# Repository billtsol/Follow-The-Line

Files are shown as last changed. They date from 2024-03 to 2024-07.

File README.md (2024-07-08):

# Arduino Follow-the-Line Project with QTR Reflectance Sensor

This project is an example of how to use an Arduino board, QTR reflectance sensor, and a motor driver shield to create a simple follow-the-line robot.

## Requirements

To build this project, you will need the following components:

- Arduino board
- QTR reflectance sensor
- Motor driver shield
- Wheels
- Motors
- Jumper wires
- Battery

## Circuit Diagram

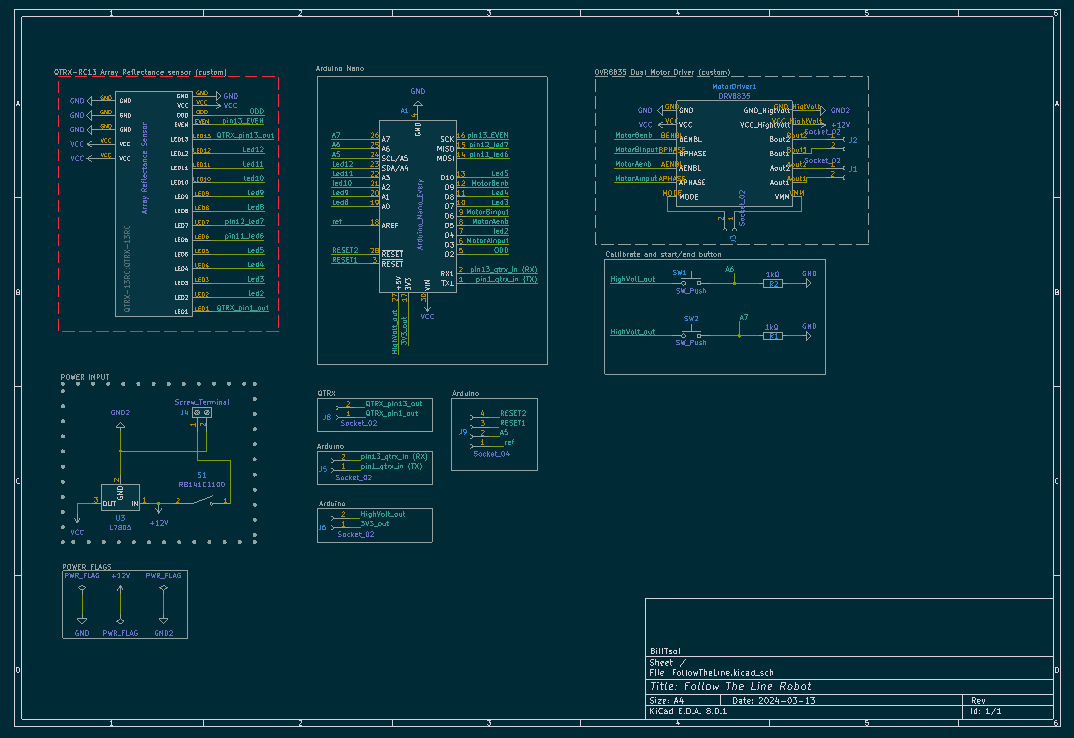
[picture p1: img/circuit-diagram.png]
Circuit Diagram


## PCB

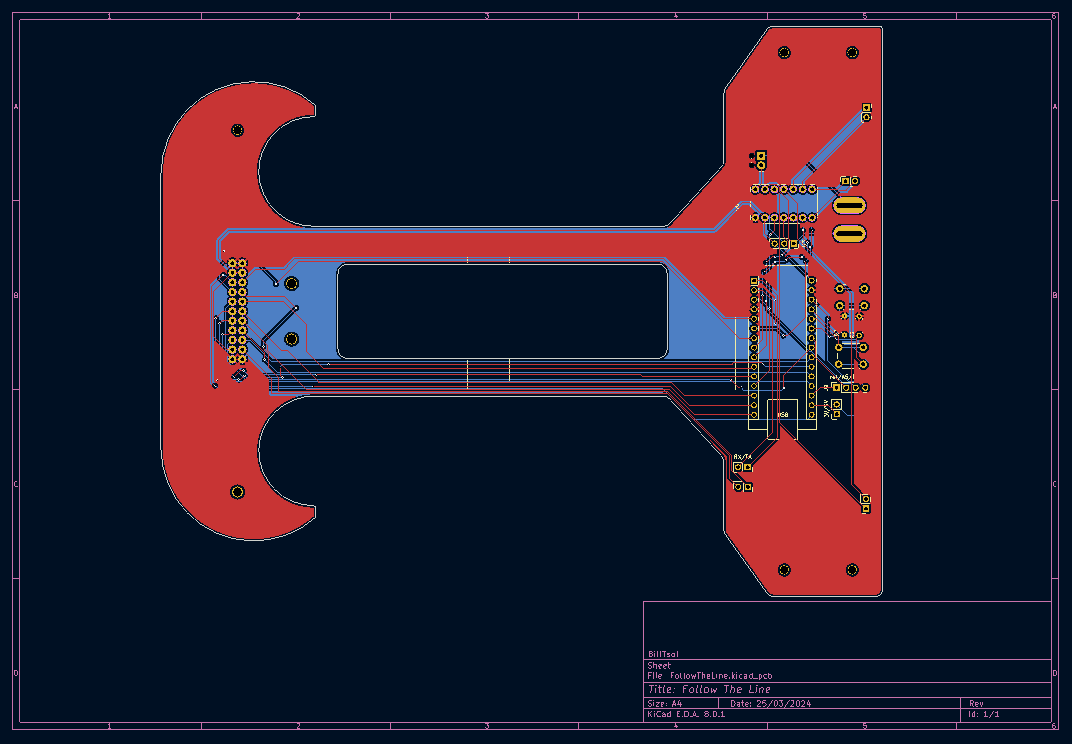
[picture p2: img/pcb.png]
PCB


## Code

The code for this project is available in the `follow_the_line.ino` file.
You can also open the `qtr_xA_example.ino` file that includes an example of how to use the QTR reflectance sensor as an analog sensor to detect the position of a line.

## Installation

1. Download the Arduino IDE from the official website and install it on your computer.
2. Connect your Arduino board to your computer via USB cable.
3. Open the Arduino IDE and open the `follow_the_line.ino` file.
4. Upload the code to your Arduino board by clicking the "Upload" button in the IDE.

## Usage

1. Connect the QTR reflectance sensor and the motor driver shield to your Arduino board according to the circuit diagram.
2. Attach the wheels and motors to the chassis.
3. Connect the motors to the motor driver shield.
4. Connect the battery to the motor driver shield.
5. Turn on the power and place the robot on a black line on a white background.
6. The robot will follow the line until it reaches the end of the line.

## Troubleshooting

If the robot does not follow the line correctly, you may need to adjust the threshold values in the code or adjust the position of the QTR reflectance sensor.

## Feature thoughts for this project:

1. Add some LEDs to make the car follow the line in the dark: By adding some LEDs to the front of the robot, it can detect the line even in low light conditions. The LEDs can be programmed to turn on when the QTR sensor detects the line and turn off when it doesn't. This feature can improve the robot's performance in darker environments.

2. Add some obstacle sensors to avoid objects in line: By adding some obstacle sensors to the sides of the robot, it can detect if there are any obstacles in its path and avoid them while staying on the line. This feature can improve the safety of the robot and prevent it from crashing into objects while following the line.

## Final Images

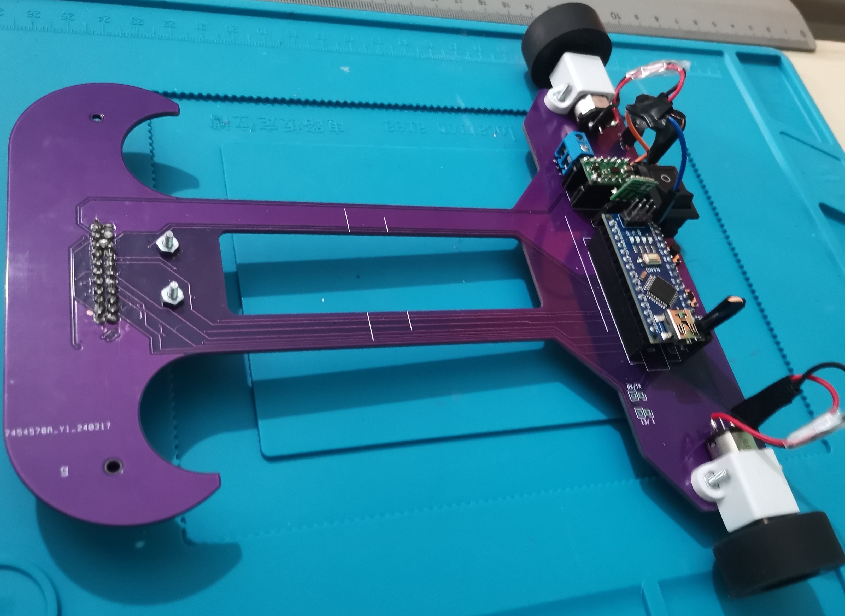
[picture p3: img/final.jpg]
final

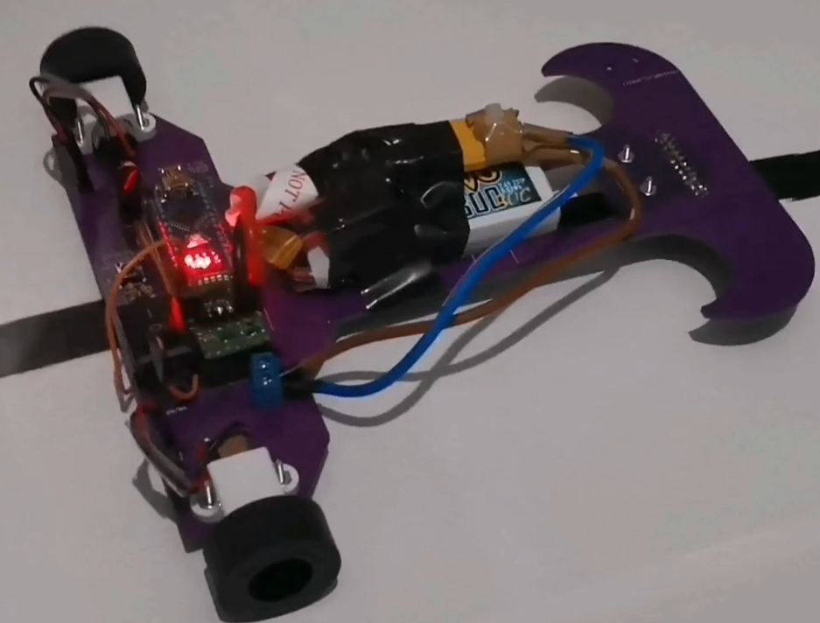
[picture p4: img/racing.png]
racing


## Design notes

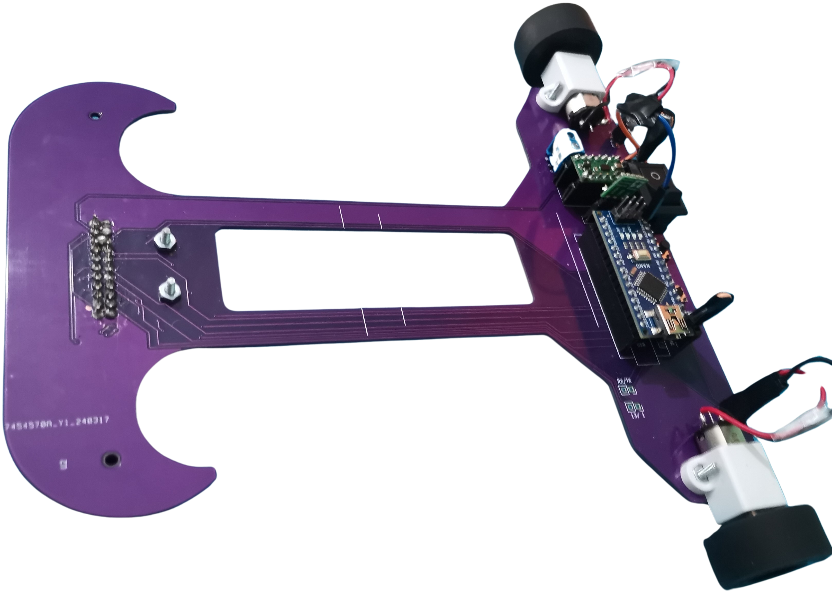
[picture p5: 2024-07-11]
img/final-removebg.png

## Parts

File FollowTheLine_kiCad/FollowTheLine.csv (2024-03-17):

Source: | C:\Users\iis22\OneDrive\Documents\github\Follow-The-Line\FollowTheLine_kiCad\FollowTheLine.kicad_sch
Date: | 2024-03-17T01:34:20+0200
Tool: | Eeschema 8.0.0
Generator: | C:\Program Files\KiCad\8.0\bin\scripting\plugins/bom_csv_grouped_by_value_with_fp.py
Component Count: | 17
Ref | Qnty | Value | Cmp name | Footprint | Description | Vendor | DNP
A1 | 1 | Arduino_Nano_Every | Arduino_Nano_Every | Module:Arduino_Nano | Arduino Nano Every
J1, J2, J3, J5, J6, J8 | 6 | Socket_02 | Conn_01x02_Socket | Connector_PinSocket_2.54mm:PinSocket_1x02_P2.54mm_Vertical | Generic connector, single row, 01x02, script generated
J4 | 1 | Screw_Terminal | Screw_Terminal_01x02 | TerminalBlock_Phoenix:TerminalBlock_Phoenix_MPT-0,5-2-2.54_1x02_P2.54mm_Horizontal | Generic screw terminal, single row, 01x02, script generated (kicad-library-utils/schlib/autogen/connector/)
J9 | 1 | Socket_04 | Conn_01x04_Socket | Connector_PinSocket_2.54mm:PinSocket_1x04_P2.54mm_Vertical | Generic connector, single row, 01x04, script generated
MotorDriver1 | 1 | DRV8835 | DRV8835 | Library:DRV8835
R1, R2 | 2 | 1kΩ | R | Resistor_THT:R_Axial_DIN0204_L3.6mm_D1.6mm_P5.08mm_Horizontal | Resistor
S1 | 1 | RB141C1100 | RB141C1100 | RB141C1100:SW_RB141C1100
SW1, SW2 | 2 | SW_Push | SW_Push | Button_Switch_THT:SW_PUSH_6mm | Push button switch, generic, two pins
U2 | 1 | Array Reflectance Sensor | QTR-8A | QTRX-13RC:QTRX-13RC
U3 | 1 | L7805 | L7805 | Connector_PinSocket_2.54mm:PinSocket_1x03_P2.54mm_Vertical | Positive 1.5A 35V Linear Regulator, Fixed Output 5V, TO-220/TO-263/TO-252

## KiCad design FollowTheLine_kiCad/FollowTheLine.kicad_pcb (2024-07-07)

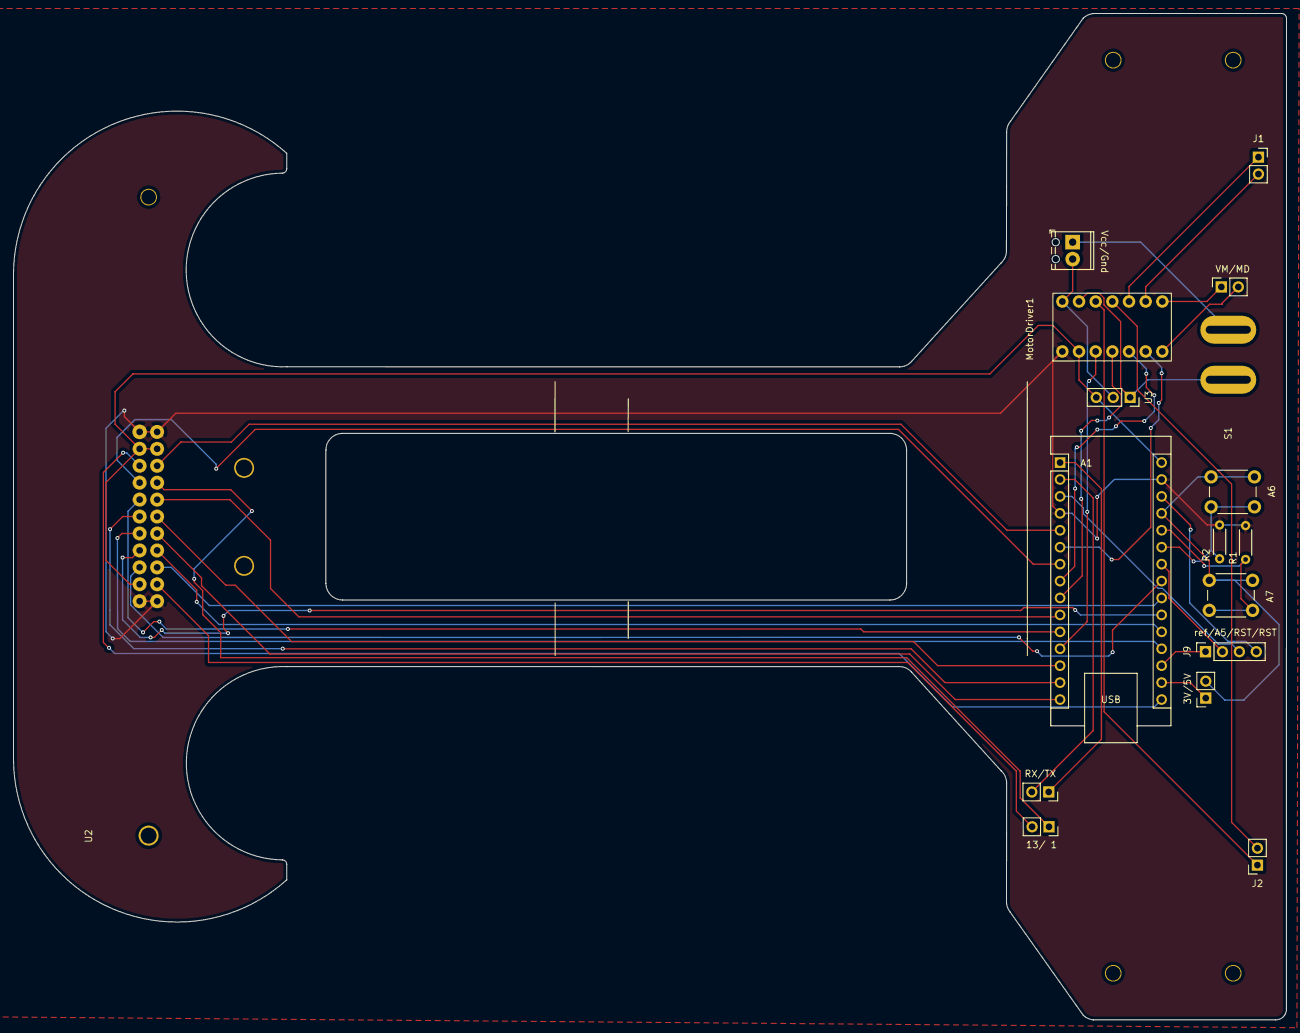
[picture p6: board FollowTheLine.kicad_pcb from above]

Board: 2 copper layers, 191.0 x 151.0 mm, 17 parts (0 on the bottom side), 40 nets.

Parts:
A1: Arduino_Nano_Every; Arduino_Nano
A6, A7: SW_Push; SW_PUSH_6mm
J1, J2, J3, J5, J6, J18: Socket_02; PinSocket_1x02_P2.54mm_Vertical
J4: Screw_Terminal; TerminalBlock_Phoenix_MPT-0,5-2-2.54_1x02_P2.54mm_Horizontal
J9: Socket_04; PinSocket_1x04_P2.54mm_Vertical
MotorDriver1: DRV8835
R1, R2: 1kΩ; R_Axial_DIN0204_L3.6mm_D1.6mm_P5.08mm_Horizontal
S1: RB141C1100; SW_RB141C1100
U2: Array Reflectance Sensor; QTRX-13RC
U3: L7805; PinSocket_1x03_P2.54mm_Vertical

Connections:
+12V: MotorDriver1.VCC_HightVolt, S1.2, U3.1 (IN)
/3V3_out: A1.17 (3V3), J6.1
/A5: A1.24 (SCL/A5), J9.2
/A6: A1.25 (A6), A6.2, R2.1
/A7: A1.26 (A7), A7.2, R1.1
/HighVolt_out: A1.27 (+5V), A6.1, A7.1, J6.2
/Led3: A1.10 (D7), U2.LED3
/Led4: A1.11 (D8), U2.LED4
/Led5: A1.13 (D10), U2.LED5
/Led8: A1.19 (A0), U2.LED8
/Led9: A1.20 (A1), U2.LED9
/Led11: A1.22 (A3), U2.LED11
/Led12: A1.23 (SDA/A4), U2.LED12
/MotorAenb: A1.8 (D5), MotorDriver1.AENBL
/MotorAinput: A1.6 (D3), MotorDriver1.APHASE
/MotorBenb: A1.12 (D9), MotorDriver1.BENBL
/MotorBinput: A1.9 (D6), MotorDriver1.BPHASE
/ODD: A1.5 (D2), U2.ODD
/QTRX_pin1_out: J18.1, U2.LED1
/QTRX_pin13_out: J18.2, U2.LED13
/RESET1: A1.3 (~RESET), J9.3
/RESET2: A1.28 (~RESET), J9.4
/led2: A1.7 (D4), U2.LED2
/led10: A1.21 (A2), U2.LED10
/pin1_qtrx_in (TX): A1.1 (TX1), J5.1
/pin11_led6: A1.14 (MOSI), U2.LED6
/pin12_led7: A1.15 (MISO), U2.LED7
/pin13_EVEN: A1.16 (SCK), U2.EVEN
/pin13_qtrx_in (RX): A1.2 (RX1), J5.2
/ref: A1.18 (AREF), J9.1
GND: A1.4 (GND), A1.29 (GND), MotorDriver1.GND, R1.2, R2.2, U2.GND
GND2: J4.2, MotorDriver1.GND_HigtVolt, U3.2 (GND)
unnamed: J1.1, MotorDriver1.Aout2
unnamed: J1.2, MotorDriver1.Aout1
unnamed: J2.1, MotorDriver1.Bout2
unnamed: J2.2, MotorDriver1.Bout1
unnamed: J3.1, MotorDriver1.VMM
unnamed: J3.2, MotorDriver1.MODE
unnamed: J4.1, S1.1
VCC: A1.30 (VIN), MotorDriver1.VCC, U2.VCC, U3.3 (OUT)

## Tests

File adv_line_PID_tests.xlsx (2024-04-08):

Kp | Ki | Kd |  | MAX | Base
0.08 | 0.0005 | 0.5 | oxi | 170 | 100
 |  | 0.4 | oxi
 |  | 0.3 | oxi
0.09 |  |  | kati
 |  | 0.5 | oxi
0.1 |  | 0.3 | nai
0.2 |  |  | oxi
 |  | 0.2 | oxi
0.095 |  |  | nai alla den mpainei kentro
 |  | 0.3
0.095 | 0.005 | 0.25 | nai | 200 | 100
0.095 |  | 0.15 | nai | 200 | 100
0.09 | 0.004 | 0.15
0.09 | 0.003 | 0.1 | ΝΑΙ | 200 | 100
0.08 | 0.003 | 0.1 | ΝΑΙ | 255 | 100
0.07 | 0.003 | 0.1 | oxi

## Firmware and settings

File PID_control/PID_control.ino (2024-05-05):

// Length = 5m

/*************************************************************************
 * QRT-X GPIO pins declaration
 *************************************************************************/
#include <QTRSensors.h>

QTRSensors qtr;
const uint8_t SensorCount = 11;
uint16_t sensorValues[SensorCount];

const int oddPin = 2;
const int evenPin = 2;

/*************************************************************************
 * DRV8835 GPIO pins declaration
 *************************************************************************/
// int mode = ; Auto ON

// Left Motor
int aphase = 3;
int aenbl = 5;

// Right Motor
int bphase = 6;
int benbl = 9;

int base_speed = 100;

int max_speed = 200;
int min_speed = -200;

/*************************************************************************
* PID controler variables
*************************************************************************/
float Kp = 0.09;  //related to the proportional control term;
                   //change the value by trial-and-error (ex: 0.07). 0.03
float Ki = 0.0003; //related to the integral control term;
                   //change the value by trial-and-error (ex: 0.0008). 0.00001
float Kd = 0.08;  //related to the derivative control term;
                   //change the value by trial-and-error (ex: 0.6). 0.3

int P = 0;
int I = 0;
int D = 0;

int lastError = 0;

/*************************************************************************
* Buttons pins declaration
*************************************************************************/
int buttoncalibrate = A7;
int startButton = A6;

int stop = 0;
unsigned long startTime = 0;
int timer_duration = 7000; // Define timer duration in milliseconds (5 seconds)

void setup() {
  // Serial.begin(9600);

  // QTRX Set up
  qtr.setTypeRC();
  qtr.setSensorPins((const uint8_t[]){4, 7, 8, 10, 11, 12, A0, A1, A2, A3, A4}, SensorCount);
  qtr.setEmitterPin(oddPin);

  // Motors Set up
  pinMode(aphase, OUTPUT);
  pinMode(aenbl, OUTPUT);
  pinMode(bphase, OUTPUT);
  pinMode(benbl, OUTPUT);

  pinMode(13,OUTPUT);

  pinMode(buttoncalibrate, INPUT);
  pinMode(startButton, INPUT);

  digitalWrite(13, LOW);

}

void loop() {
  while( analogRead(buttoncalibrate) == 0); // Start Calibration A6

  calibration(); // Calibrate the robot for 10 seconds

  forward_movement(0,0);

  while( analogRead(startButton) == 0); // Start Calibration A6

  delay(1500);

  startTime = millis();

  while (1){
    unsigned long currentTime = millis();
    if (
      (end() == 1 || stop == 1) &&
      ( currentTime - startTime >= timer_duration )
    ){
      forward_movement(0,0);
      stop = 1;
    }else{
      PID_control();
    }
  }

}

void PID_control(){
  uint16_t position = qtr.readLineBlack(sensorValues);

  int error = 5000 - position;

  P = error;
  I = I + error;
  D = error - lastError;

  lastError = error;

  float motor_speed = P*Kp + I*Ki + D*Kd;
  int motor_speed_A = base_speed - motor_speed;
  int motor_speed_B = base_speed + motor_speed;

  // Set max speed
  if (motor_speed_A > max_speed) { motor_speed_A = max_speed; }
  if (motor_speed_B > max_speed) { motor_speed_B = max_speed; }

  // Set min speed
  if (motor_speed_A < min_speed) { motor_speed_A = min_speed; }
  if (motor_speed_B < min_speed) { motor_speed_B = min_speed; }

  forward_movement(motor_speed_A, motor_speed_B);

  // Serial.print('\n');
  // Serial.print("A: ");
  // Serial.print(motor_speed_A);
  // Serial.print('\n');
  // Serial.print("B: ");
  // Serial.print(motor_speed_B);

  // Serial.print('\n');
}

void custom_corners(){

  // Right
  if (
    sensorValues[6] > 600 &&
    sensorValues[7] > 600 &&
    sensorValues[8] > 600 &&
    sensorValues[9] > 600 &&
    sensorValues[10] > 600 &&

    sensorValues[0] < 600
  ) {
    forward_movement(75, 250);
    delay(250);
  }
  // Left
  if (
    sensorValues[0] > 600 &&
    sensorValues[1] > 600 &&
    sensorValues[2] > 600 &&
    sensorValues[3] > 600 &&
    sensorValues[4] > 600 &&

    sensorValues[10] < 600
  ){
    forward_movement(250, 75);
    delay(250);
  }

  forward_movement(base_speed,base_speed);
}

void forward_movement(int speedA, int speedB) {
  if (speedA < 0) {
    speedA = 0 - speedA;
    digitalWrite(aphase, LOW);
  }
  else {
    digitalWrite(aphase, HIGH);
  }

  if (speedB < 0) {
    speedB = 0 - speedB;
    digitalWrite(bphase, HIGH);
  }
  else {
    digitalWrite(bphase, LOW);
  }

  analogWrite(aenbl, speedA);
  analogWrite(benbl, speedB);
}

void calibration() {
  digitalWrite(13,HIGH);
  // int r = -1;
  // int l = 1;
  for (uint16_t i = 0; i < 400; i++) {
  //   if (i % 20 == 0){
  //     forward_movement(75 * r, 75 *  l);
  //     r = -r;
  //     l = -l;
  //   }
    qtr.calibrate();
  }
  digitalWrite(13,LOW);
}

int end(){
  int zero_one = sensorValues[0] + sensorValues[1] ; // Black
  int two = sensorValues[2]; // White ?
  int three = sensorValues[3]; // White
  int seven = sensorValues[7]; // White
  int eight = sensorValues[8]; // White ?
  int nine_ten =  + sensorValues[9] + sensorValues[10]; // Black

  if (
    (zero_one > 900) &&
    (sensorValues[5] > 500) &&
    (nine_ten > 900)
  ){
    return 1;
  }
  return 0;
}

//  Testing functions
void qtrx_test(){
  uint16_t position = qtr.readLineBlack(sensorValues);

  for (uint8_t i = 0; i < SensorCount; i++)
  {

    Serial.print(sensorValues[i]);
    Serial.print('\t');
  }
  Serial.println(position);

  delay(250);
}

void pid_test(int position,int motor_speed){

  Serial.print("\n");
  Serial.print("Line: ");
  Serial.println(position);
  Serial.print("\n");

  Serial.print("P: ");
  Serial.print(P);
  Serial.print('\t');
  Serial.print("I: ");
  Serial.print(I);
  Serial.print('\t');
  Serial.print("D: ");
  Serial.print(D);
  Serial.print('\n');

  Serial.print("Kp: ");
  Serial.print(Kp);
  Serial.print('\t');
  Serial.print("Ki: ");
  Serial.print(Ki);
  Serial.print('\t');
  Serial.print("Kd: ");
  Serial.print(Kd);
  Serial.print('\t');

  Serial.print("sum: ");
  Serial.print(motor_speed);
  Serial.print('\n');
  Serial.print('\n');

  // delay(500);
}

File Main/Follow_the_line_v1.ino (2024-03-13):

#include <QTRSensors.h> //Make sure to install the library

/*************************************************************************
* QTR GPIO pins declaration
*************************************************************************/

QTRSensors qtr;
const uint8_t SensorCount = 11;
uint16_t sensorValues[SensorCount];

const int oddPin = 2;
const int evenPin = 1;

/*************************************************************************
* DRV8835 GPIO pins declaration
*************************************************************************/
int mode = 13;
int aphase = 7;
int aenbl = 10;
int bphase = 4;
int benbl = 9;

/*************************************************************************
* Buttons pins declaration
*************************************************************************/
int buttoncalibrate = 12; //or pin A3
int buttonstart = 12;

/*************************************************************************
* PID controler variables
*************************************************************************/
float Kp = 0.0007; //related to the proportional control term; 
              //change the value by trial-and-error (ex: 0.07).
float Ki = 0.001; //related to the integral control term; 
              //change the value by trial-and-error (ex: 0.0008).
float Kd = 0.007; //related to the derivative control term; 
              //change the value by trial-and-error (ex: 0.6).

int P = 0;
int I = 0;
int D = 0;

int lastError = 0;

int base_speed_A = 40;
int base_speed_B = 40;

void setup() {
  Serial.begin(9600);
  
  qtr.setTypeRC();
  qtr.setSensorPins((const uint8_t[]){ A0, A1, A2, A3, A4, A5, 3, 5, 6, 8, 11  }, SensorCount);
  qtr.setEmitterPins(oddPin, evenPin);

  pinMode(mode, OUTPUT);
  pinMode(aphase, OUTPUT);
  pinMode(aenbl, OUTPUT);
  pinMode(bphase, OUTPUT);
  pinMode(benbl, OUTPUT);

  digitalWrite(mode, HIGH); //one of the two control interfaces 

  pinMode(LED_BUILTIN, OUTPUT);

  while (digitalRead(buttoncalibrate) == LOW) { } // the main function won't start until the robot is calibrated

  calibration(); //calibrate the robot for 10 seconds

  while (digitalRead(buttoncalibrate) == LOW) { } // the main function won't start until the robot is calibrated

}

void loop() {
  PID_control();
}

void PID_control(){
  uint16_t position = qtr.readLineBlack(sensorValues); 

  int error = 5000 - position;
 
  P = error;
  I = I + error;
  D = error - lastError;
  
  lastError = error;

  float motor_speed =( P*Kp + I*Ki + D*Kd)/10;
  int motor_speed_A = base_speed_A - motor_speed; 
  int motor_speed_B = base_speed_B + motor_speed;

  if (position > 4500 && position < 5500){
    motor_speed_A = 40; 
    motor_speed_B = 40;

  }

  if (motor_speed_A > 80) {
    motor_speed_A = 80;
  }
  if (motor_speed_B > 80) {
    motor_speed_B = 80;
  }
  if (motor_speed_A < -80) {
    motor_speed_A = -80;
  }
  if (motor_speed_B < -80) {
    motor_speed_B = -80;
  }


  Serial.print("\n");
  Serial.print("Line: ");
  Serial.println(position);
  Serial.print("\n");
  
  Serial.print("P: ");
  Serial.print(P);
  Serial.print('\t');
  Serial.print("I: ");
  Serial.print(I);
  Serial.print('\t');
  Serial.print("D: ");
  Serial.print(D);
  Serial.print('\n');

  Serial.print("Kp: ");
  Serial.print(Kp);
  Serial.print('\t');
  Serial.print("Ki: ");
  Serial.print(Ki);
  Serial.print('\t');
  Serial.print("Kd: ");
  Serial.print(Kd);
  Serial.print('\t');

  Serial.print("sum: ");
  Serial.print(motor_speed);
  Serial.print('\n');
  Serial.print('\n');
 
  // Serial.print("A: ");
  // Serial.println(motor_speed_A);
  
  // Serial.print("B: ");
  // Serial.println(motor_speed_B);

  forward_movement(motor_speed_A, motor_speed_B);

  // delay(3000);
}


void forward_movement(int speedA, int speedB) {
  if (speedA < 0) {
    speedA = 0 - speedA;
    digitalWrite(aphase, LOW);
  }
  else {
    digitalWrite(aphase, HIGH);
  }
  if (speedB < 0) {
    speedB = 0 - speedB;
    digitalWrite(bphase, HIGH);
  }
  else {
    digitalWrite(bphase, LOW);
  }
  analogWrite(aenbl, speedA);
  analogWrite(benbl, speedB);

  Serial.print("A: ");
  Serial.println(speedA);
  
  Serial.print("B: ");
  Serial.println(speedB);
}

void calibration() {
  digitalWrite(LED_BUILTIN, HIGH);
  for (uint16_t i = 0; i < 400; i++)
  {
    qtr.calibrate();
  }
  digitalWrite(LED_BUILTIN, LOW);
}

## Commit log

2023-04-12 i add the example info for qtr sensor
2023-04-12 add follow the line arduino file
2024-01-23 qtr sensor code
2024-01-25 Control motors
2024-03-06 motor driver test code
2024-03-06 QTR-RC sensor test code
2024-03-10 Change some connections and start the main PID system
2024-03-11 Kicad schematic first idea - Custom qtr and motor driver footprint (what have issues)
    [FollowTheLine.kicad_pcb, FollowTheLine.kicad_sch]
2024-03-12 First version of follow the line pcb - only schematic
    [FollowTheLine.kicad_pcb]
2024-03-15 Follow the line. PCB version v2
    [FollowTheLine.kicad_pcb, FollowTheLine.kicad_sch]
2024-03-16 kicad footprint version 2
    [FollowTheLine.kicad_pcb]
2024-03-17 pcb completed
    [FollowTheLine.csv, FollowTheLine.kicad_pcb, FollowTheLine.kicad_sch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]
2024-03-17 First order. 'gerber files'
    [FollowTheLine-B_Cu.gbr, FollowTheLine-B_Mask.gbr, FollowTheLine-B_Paste.gbr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]
2024-03-22 Follow the line, pcb, Kicad Last version. (production).
2024-03-24 Make test functions, and complete the start and callibration buttons.
2024-03-25 Small changes in kiCad PCB
    [FollowTheLine.kicad_pcb]
2024-03-29 follow the line robot with qtrx sensor
2024-03-29 Small Changes in kiCad files
2024-04-05 More accurate hp,ki,pd. not working
    [adv_line.ino]
2024-04-08 PID controller completed. base speed 100 max speed 200.
    [adv_line_PID_tests.xlsx]
2024-05-05 Add the circuit diagram (pdf)
2024-06-03 kicad backups
2024-06-12 pcb image
2024-07-07 implement circuit and pcb diagrams
    [FollowTheLine.kicad_pcb]
